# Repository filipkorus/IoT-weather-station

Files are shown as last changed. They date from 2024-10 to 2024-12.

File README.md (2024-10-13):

### Development
- [backend README](backend/README.md)
- [frontend README](frontend/README.md)

### Production
Build:
```shell
docker compose -f compose-master.yml -f compose-local.yml build
```

Start:
```shell
docker compose -f compose-master.yml -f compose-local.yml up -d
```

**NOTE:** [example-compose-local.yml](example-compose-local.yml) file is an example how [compose-local.yml](compose-local.yml) file should look like.

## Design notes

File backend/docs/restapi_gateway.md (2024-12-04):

# Gateway REST API Documentation

This API provides functionalities for managing gateways and their associated devices. Below are the details of each endpoint.

### 1. Fetch Gateway Pairing Code (to the Gateway)

**URL**: `/api/gateway/init`
**Method**: `POST`

#### Request
**Description**: This endpoint is used by a gateway device to initialize its pairing process. It generates or returns an existing pairing code if the gateway is not already paired with a user.

No request body is required because the gateway's API key is sent in the authorization header.

#### Response
- **Status Code**: `200 OK` is returned if the gateway is successfully initialized.
  ```json
  {
    "username": "string (username of the gateway owner)"
  }
  ```
- **Status Code**: `403 Forbidden` is returned if the gateway is not paired yet but the pairing code has been created.
  ```json
  {
    "pairingCode": "string (6-digit pairing code)"
  }
  ```
- **Status Code**: `500 Internal Server Error` is returned if the owner of the gateway is not found.
  ```json
    {
      "message": "Server Error: User owning gateway (id={gatewayId}) not found"
    }
  ```
- **Status Code**: `500 Internal Server Error` is returned if the pairing code could not be generated.
  ```json
    {
      "message": "Server Error: Pairing code could not be created"
    }
  ```
  
### 2. Insert Gateway Pairing Code (from the User)

**URL**: `/api/gateway/pariring-code`
**Method**: `POST`

#### Request
**Description**: This endpoint is used by a user to pair a gateway device with their account. The user must provide the 6-digit pairing code displayed on the gateway device.

This endpoint requires the user to be logged in, i.e. have a valid access token in the Authorization header (`Bearer accesstoken`).

- **Body Parameters**:
  ```json
  {
    "pairingCode": "string (6-digit pairing code inserted by the user)"
  }
  ```
  
#### Response
- **Status Code**: `200 OK` is returned if the gateway is successfully paired with the user.
  ```json
  {
    "message": "Gateway paired"
  }
  ```
- **Status Code**: `400 Bad Request` is returned if the `pairingCode` body field is missing or invalid.
  ```json
  {
    "message": "Missing or invalid body fields.",
    "errors": {
      "pairingCode": ["error message"]
    }
  }
  ```
- **Status Code**: `404 Not Found` is returned if the pairing code is invalid or the gateway is already paired or does not exist.
  ```json
  {
    "message": "Invalid pairing code"
  }
  ```
- **Status Code**: `500 Internal Server Error` is returned if the gateway could not be paired due to a server error.
  ```json
  {
    "message": "Server Error: Gateway could not be paired"
  }
  ```

### 3. Fetch Gateway Details

**URL**: `/api/gateway/:gatewayId`
**Method**: `GET`

#### Request
**Description**: This endpoint is used to fetch the details of a gateway device when gateway ID is provided. Else, it returns the details of all gateways associated with the logged user.

This endpoint requires the user to be logged in, i.e. have a valid access token in the Authorization header (`Bearer accesstoken`).

#### Response
- When `gatewayId` is provided:
  - **Status Code**: `200 OK` is returned if the gateway details are successfully fetched.
  ```json
  {
    "gateway": {
        "id": "string (gateway ID)",
        "name": "string (gateway name)",
        "latitude": "number (latitude) - can be null",
        "longitude": "number (longitude) - can be null",
        "isPaired": "boolean (gateway pairing status)",
        "isOnline": "boolean (gateway online status)",
        "lastOnline": "string (last online timestamp)",
        "userId": "string (user ID of the gateway owner)",
        "nodes": [{
            "id": "string (node ID)",
            "name": "string (node name)",
            "gatewayId": "string (gateway ID)",
            "NodeData": [{
                "batteryLevel": 5.5 // number - battery level in volts
            }]
        }]
    }
  }
  ```
    - **Status Code**: `404 Not Found` is returned if the gateway is not found.
    ```json
    {
        "message": "Gateway (id={gatewayId}) not found"
    }
    ```
- When `gatewayId` is not provided:
  - **Status Code**: `200 OK` is returned if gateways details are successfully fetched.
  ```json
  {
    "gateways": [{
        "id": "string (gateway ID)",
        "name": "string (gateway name)",
        "latitude": "number (latitude) - can be null",
        "longitude": "number (longitude) - can be null",
        "isPaired": "boolean (gateway pairing status)",
        "isOnline": "boolean (gateway online status)",
        "lastOnline": "string (last online timestamp)",
        "userId": "string (user ID of the gateway owner)",
        "nodes": [{
            "id": "string (node ID)",
            "name": "string (node name)",
            "gatewayId": "string (gateway ID)",
            "NodeData": [{
                "batteryLevel": 5.5 // number - battery level in volts
            }]
        }]
    }]
  }
  ```
    - **Status Code**: `500 Internal Server Error` is returned if the server could not fetch the gateways.
    ```json
    {
        "message": "Server Error: Gateways could not be retrieved"
    }
    ```
  
### 4. Update Gateway Name, Latitude, and Longitude

**URL**: `/api/gateway/:gatewayId`
**Method**: `PUT`

#### Request
**Description**: This endpoint is used to update the name, latitude, and longitude of a gateway device when gateway ID is provided.

This endpoint requires the user to be logged in, i.e. have a valid access token in the Authorization header (`Bearer accesstoken`).

- **Body Parameters**:
  ```json
  {
    "name": "string (new gateway name) - optional",
    "latitude": "number (new latitude) - optional",
    "longitude": "number (new longitude) - optional"
  }
  ```
  
#### Response
- **Status Code**: `200 OK` is returned if the gateway name and/or latitude and longitude are successfully updated.
  ```json
  {
    "message": "Gateway name and location updated" // or "Gateway name updated" or "Gateway location updated"
  }
  ```

- **Status Code**: `400 Bad Request` is returned if the `name`, `latitude`, and `longitude` body fields are invalid.
  ```json
  {
    "message": "Missing or invalid body fields.",
    "errors": {
      "name": ["error message"],
      "latitude": ["error message"],
      "longitude": ["error message"]
    }
  }
  ```

- **Status Code**: `400 Bad Request` is also returned if no changes were made to the gateway.
  ```json
  {
    "message": "No changes made"
  }
  ```

- **Status Code**: `404 Not Found` is returned if the gateway is not found.
  ```json
  {
    "message": "Gateway (id={gatewayId}) not found"
  }
  ```
- **Status Code**: `500 Internal Server Error` is returned if the gateway name could not be updated due to a server error.
  ```json
  {
    "message": "Server Error: Gateway name could not be updated"
  }
  ```
  
### 5. Fetch Gateway Public Details

**URL**: `/api/public-gateway/:gatewayId`
**Method**: `GET`

#### Request
**Description**: This endpoint is used to fetch the public details of a gateway device when gateway ID is provided. Else, it returns the public details of all gateways.

This endpoint does not require to be logged in.

#### Response
- When `gatewayId` is provided:
  - **Status Code**: `200 OK` is returned if gateways public details are successfully fetched.
  ```json
  {
    "gateway": {
        "id": "string (gateway ID)",
        "name": "string (gateway name)",
        "latitude": "number (latitude) - can be null",
        "longitude": "number (longitude) - can be null",
        "isPaired": "boolean (gateway pairing status)",
        "isOnline": "boolean (gateway online status)",
        "lastOnline": "string (last online timestamp)",
        "userId": "string (user ID of the gateway owner)",
        "nodes": [{
            "id": "string (node ID)",
            "name": "string (node name)",
            "gatewayId": "string (gateway ID)"
        }],
        "likes": "number (number of likes)",
        "haveYouLiked": false, // boolean indication whether the user has already liked the gateway today
        "sensorData": [{ // last 5 sensor readings
            "id": 123, // number - sensor data ID
            "created": "2024-11-13T15:41:34.588Z", // string - timestamp of the sensor data
            "batteryLevel": 2.33, // number - battery level in volts
            "nodeId": "string (node ID)",
            "temperature": 23.5, // number - temperature in Celsius
            "humidity": 60, // number - humidity in percentage
            "pressure": 1013.25, // number - pressure in hPa
            "snowDepth": 0, // number - snow depth in mm (or cm)
            "pm1": 5, // number - PM1.0 in µg/m³
            "pm25": 12, // number - PM2.5 in µg/m³
            "pm10": 18 // number - PM10 in µg/m³
        }]
    }
  }
  ```
  - **Status Code**: `404 Not Found` is returned if the gateway is not found.
    ```json
    {
        "message": "Gateway (id=${gatewayId}) not found"
    }
    ```
- When `gatewayId` is not provided:
    - **Status Code**: `200 OK` is returned if gateways public details are successfully fetched.
    ```json
    {
        "gateways": [{
            "id": "string (gateway ID)",
            "name": "string (gateway name)",
            "latitude": "number (latitude) - can be null",
            "longitude": "number (longitude) - can be null",
            "isPaired": "boolean (gateway pairing status)",
            "isOnline": "boolean (gateway online status)",
            "lastOnline": "string (last online timestamp)",
            "userId": "string (user ID of the gateway owner)",
            "nodes": [{
                "id": "string (node ID)",
                "name": "string (node name)",
                "gatewayId": "string (gateway ID)"
            }],
            "likes": "number (number of likes)",
            "haveYouLiked": false, // boolean indication whether the user has already liked the gateway today
            "sensorData": [{ // last 5 sensor readings
                "id": 123, // number - sensor data ID
                "created": "2024-11-13T15:41:34.588Z", // string - timestamp of the sensor data
                "batteryLevel": 2.33, // number - battery level in volts
                "nodeId": "string (node ID)",
                "temperature": 23.5, // number - temperature in Celsius
                "humidity": 60, // number - humidity in percentage
                "pressure": 1013.25, // number - pressure in hPa
                "snowDepth": 0, // number - snow depth in mm (or cm)
                "pm1": 5, // number - PM1.0 in µg/m³
                "pm25": 12, // number - PM2.5 in µg/m³
                "pm10": 18 // number - PM10 in µg/m³
            }]
        }]
    }
    ```
    - **Status Code**: `500 Internal Server Error` is returned if the server could not fetch the gateways.
    ```json
    {
        "message": "Server Error: Gateways could not be retrieved"
    }
    ```

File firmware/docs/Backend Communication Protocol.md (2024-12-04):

# Connection to backend

All frames will have a special key to auth on the backend side.

Node ID (unique serial number): N*rrrrmmdd(00-FF)*

Gateway ID (unique serial number): G*rrrrmmdd(00-FF)*

The gateway initialises the connection by sending the `Init Frame`. If the gateway is not paired to any account, the backend returns the pairing code, which the gateway displays on the LCD screen.

The user enters the code on the website to pair it with his account. After the gateway restarts, it sends the `Init frame` again. The backend returns user data, and then the gateway starts the WS connection.

The user can pair nodes with the gateway with the button located on the case. A node sends his NID number via ESP-NOW to the gateway. The gateway saves this NID to EEPROM as a trusted node.

The gateway sends a frame via WS containing sensor data and node serial number to the backend. The backend will create a node object if it does not exist, then log data from sensors.

Node object contains also `last_message` and `battery_level` used to check if the node is alive.

### `POST` Init Frame:

##### Request:

    {
    	uid: *GatewayId*
    }

##### Response:

If not paired:
Status: `403`

    {
    	pair_code: *6 char code*
    }

If paired:
Status: `200`

    {
    	user_name: *Name of the user*
    }

### `WS` Data Frame:

#### Gateway to backend:

    {
    	type: 'sensors'
    	node_id:
    	battery_level: 5-8,4 (V)
    	temperature: -5.5 (*C)
    	humidity: 50 (0-100%)
    	pressure: 1010 (hPa)
    	snow_depth: 50 (cm)
    	pm1: ?
    	pm25: ?
    	pm10: ?
    }

#### Backend to Gateway:

    {
    	type: 'likes'
    	likes: *int*
    }

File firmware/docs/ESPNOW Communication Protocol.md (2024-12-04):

# Frame struct

```C++
typedef struct struct_message
{
    char nodeId[16];
    float batteryLevel; // volts
    float temperature;  // °C
    float humidity;     // %
    float pressure;     // hPa
    int32_t snowDepth;  // cm
    uint32_t pm1;       // ug/m³
    uint32_t pm25;      // ug/m³
    uint32_t pm10;      // ug/m³
    bool pair;
} struct_message;
```

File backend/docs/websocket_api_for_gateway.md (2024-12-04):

# Gateway WebSocket API Documentation

This API provides functionalities for the gateway WebSocket server. Below are the details of each type of message.

Authentication is done using the gateway's API key in the `Authorization` header.

### 1. Sending Node sensor data (from the Gateway, to the Server)

**Description**: Sends sensor data from a node to the server.

**JSON Body**:
```json
{
  "type": "sensors",
  "nodeId": "Nrrrrmmdd(00-FF)", // string (Node ID)
  "batteryLevel":  5.5,   // float (Battery level in volts)
  "temperature": 25.5,    // float (Temperature in Celsius)
  "humidity":  70.5,      // float (Humidity in percentage)
  "pressure": 1013.25,    // float (Pressure in hPa)
  "snowDepth":  42.0,     // float (Snow depth in cm)
  "pm1": 10.0,            // float (PM1 in µg/m³)
  "pm25":  25.0,          // float (PM2.5 in µg/m³)
  "pm10": 50.0,           // float (PM10 in µg/m³)
}
```

### 2. Receiving like count data (from the Server, to the Gateway)

**Description**: Sends the like count data to the gateway.

**JSON Body**:
```json
{
  "type": "likes",
  "gatewayId": "Grrrrmmdd(00-FF)", // string (Node ID)
  "likes":  10 // integer (Like count)
}
```

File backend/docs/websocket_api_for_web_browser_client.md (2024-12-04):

# Web Browser Client WebSocket API Documentation

This API provides functionalities for the web browser client WebSocket server. Below are the details of each type of message.

Every client trying to connect without an API key in the `Authorization` header, is assumed to be a web browser client.

### 1. Receiving live sensor data (from the Server, to the Web Browser Client)

**Description**: Sends live sensor data to the web browser client.

**JSON Body**:
```json
{
  "type": "sensors-to-client",
  "gatewayId": "Grrrrmmdd(00-FF)", // string (Gateway ID)
  "nodeId": "Nrrrrmmdd(00-FF)",    // string (Node ID)
  "sensorData": {
    "batteryLevel":  5.5,   // float (Battery level in volts)
    "temperature": 25.5,    // float (Temperature in Celsius)
    "humidity":  70.5,      // float (Humidity in percentage)
    "pressure": 1013.25,    // float (Pressure in hPa)
    "snowDepth":  42.0,     // float (Snow depth in cm)
    "pm1": 10.0,            // float (PM1 in µg/m³)
    "pm25":  25.0,          // float (PM2.5 in µg/m³)
    "pm10": 50.0,            // float (PM10 in µg/m³)
    "created": "2024-11-13T15:41:34.588Z" // string - timestamp of the sensor data",    // string (Date and time of the measurement)
  }
}
```

### 2. Sending 'like' (from the Web Browser Client, to the Server)

**Description**: Sends the like to the server.

**Request JSON Body**:
```json
{
  "type": "likes",
  "gatewayId": "Grrrrmmdd(00-FF)" // string (Gateway ID)
}
```

**Response JSON Body**:
- If the like was successfully sent (FYI: one like from one `(IP address, User Agent)` pair per day per each Gateway is allowed):
```json
{
  "type": "likes",
  "gatewayId": "Grrrrmmdd(00-FF)", // string (Gateway ID)
  "likes":  10 // integer (Like count)
}
```

- Else, if the like was not successful - e.g., the user has already liked:
```json
{
  "type": "likes-error-response",
  "error": true,
  "gatewayId": "Grrrrmmdd(00-FF)", // string (Gateway ID)
  "message": "You have already liked" // string (Error message)
}
```

### 3. Sending 'remove like' request (from the Web Browser Client, to the Server)

**Description**: Sends the 'remove like' request to the server.

**Request JSON Body**:
```json
{
  "type": "dislike",
  "gatewayId": "Grrrrmmdd(00-FF)" // string (Gateway ID)
}
```

**Response JSON Body**:
- If the request was successful and the like was removed:
```json
{
  "type": "likes",
  "gatewayId": "Grrrrmmdd(00-FF)", // string (Gateway ID)
  "likes":  9 // integer (Like count)
}
```

- Else, if the request was not successful - e.g., the user has not liked yet:
```json
{
  "type": "dislike-error-response",
  "error": true,
  "gatewayId": "Grrrrmmdd(00-FF)", // string (Gateway ID)
  "message": "You have not liked yet" // string (Error message)
}
```

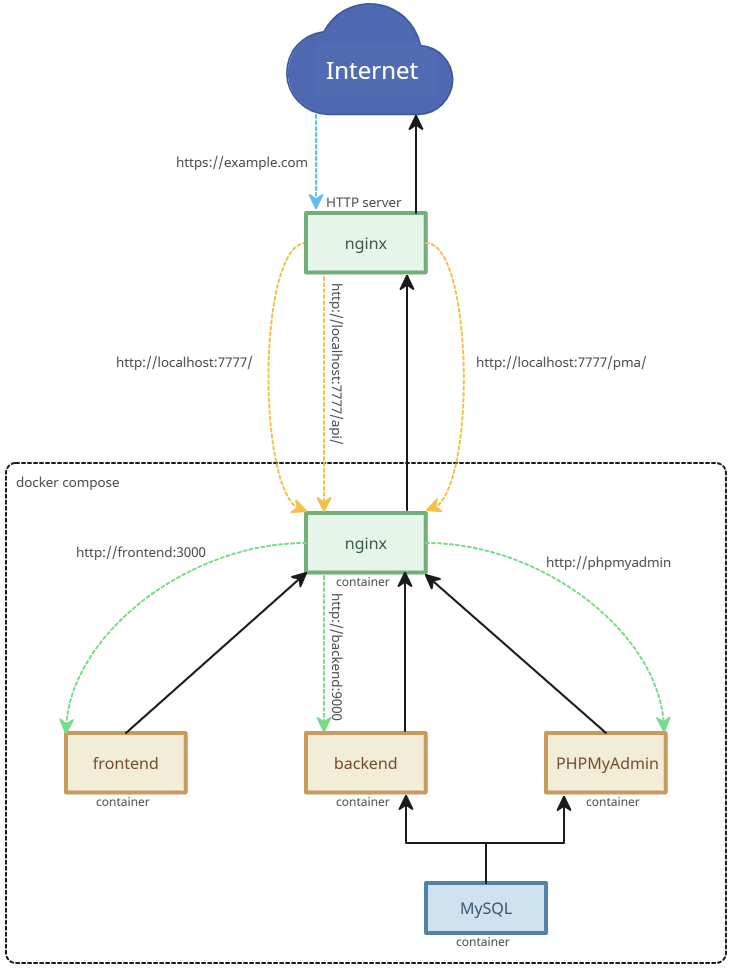
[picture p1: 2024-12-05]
backend/docs/architecture.png

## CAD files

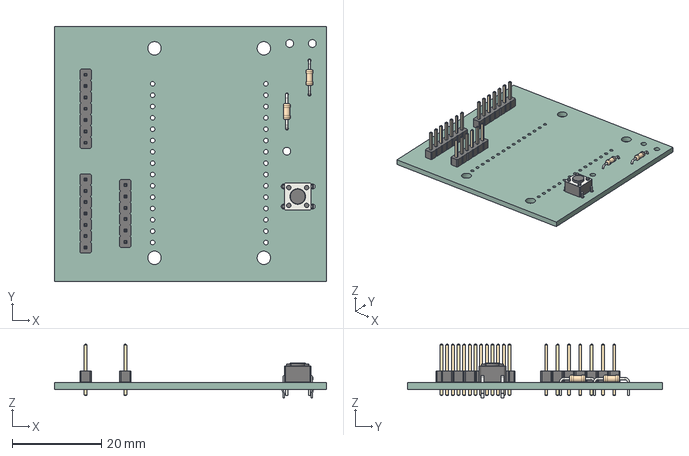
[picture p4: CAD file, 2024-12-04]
PCBs/node/node.step
61.0 x 57.2 x 12.0 mm
node PCB

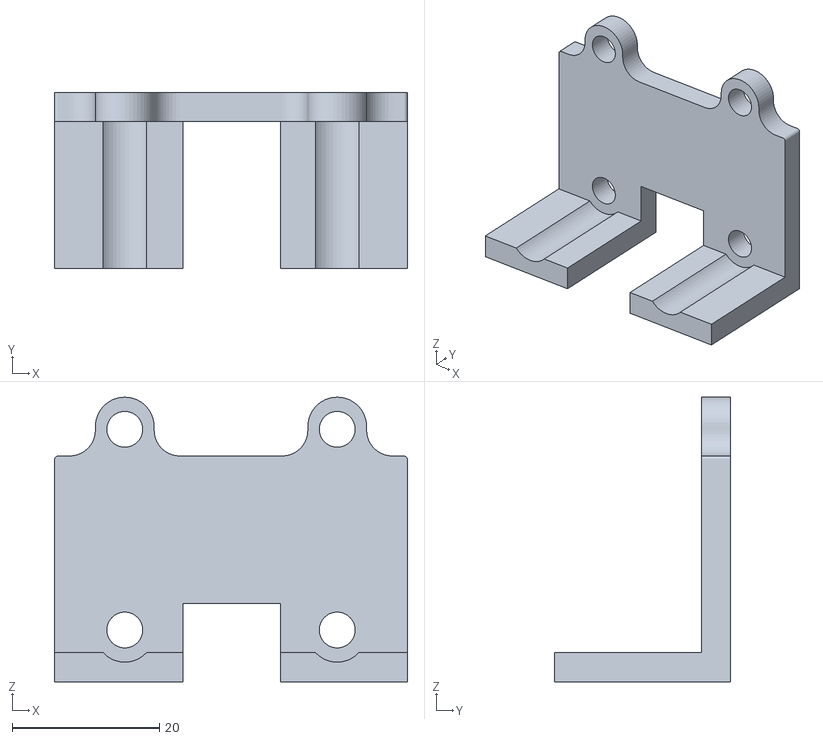
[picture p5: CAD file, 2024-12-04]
STL/LidarMount.stl
48.0 x 24.0 x 38.7

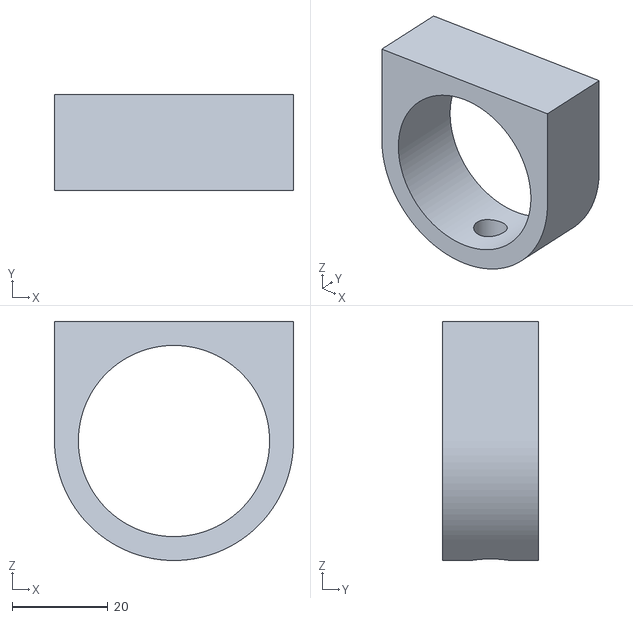
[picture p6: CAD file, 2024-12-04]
STL/LidMount.stl
50.0 x 20.0 x 50.0

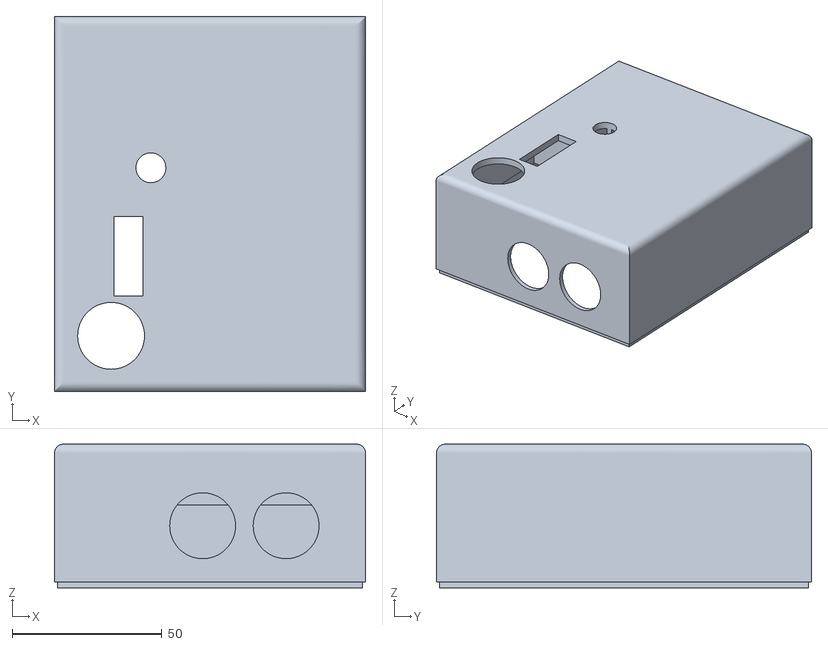
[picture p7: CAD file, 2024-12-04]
STL/case.stl
103.8 x 125.2 x 48.0

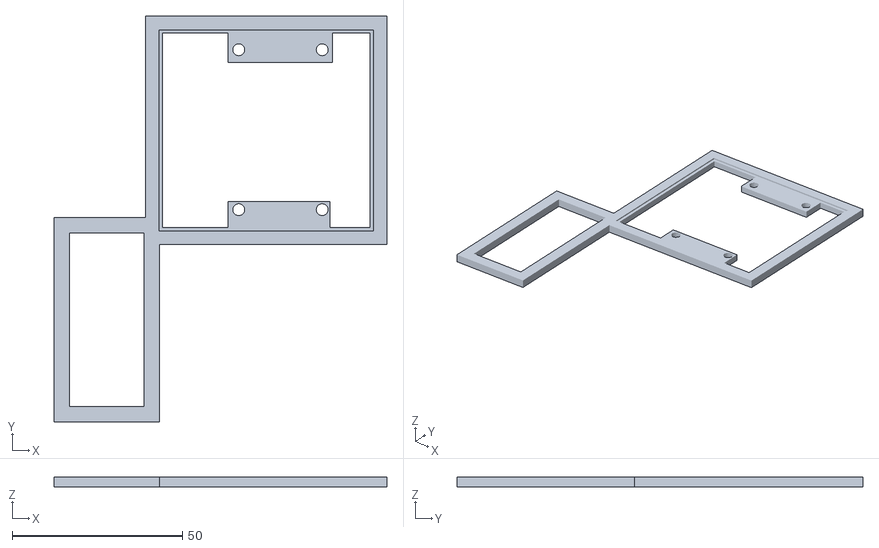
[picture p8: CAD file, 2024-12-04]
STL/backplate.stl
97.8 x 119.2 x 3.00

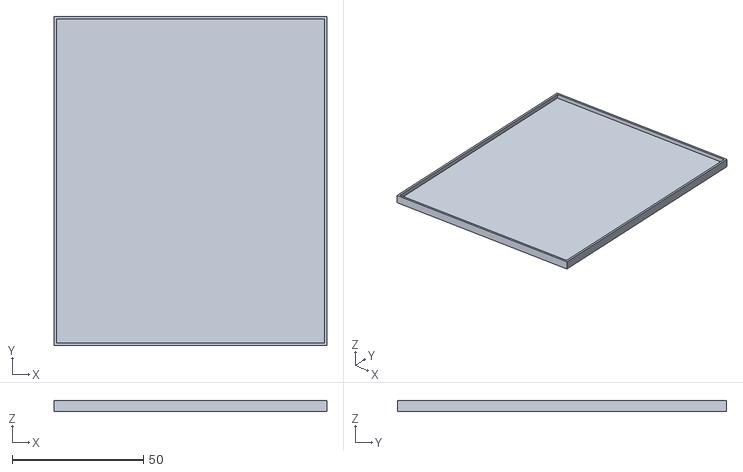
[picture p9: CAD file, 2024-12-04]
STL/Lid.stl
103.8 x 125.2 x 4.00

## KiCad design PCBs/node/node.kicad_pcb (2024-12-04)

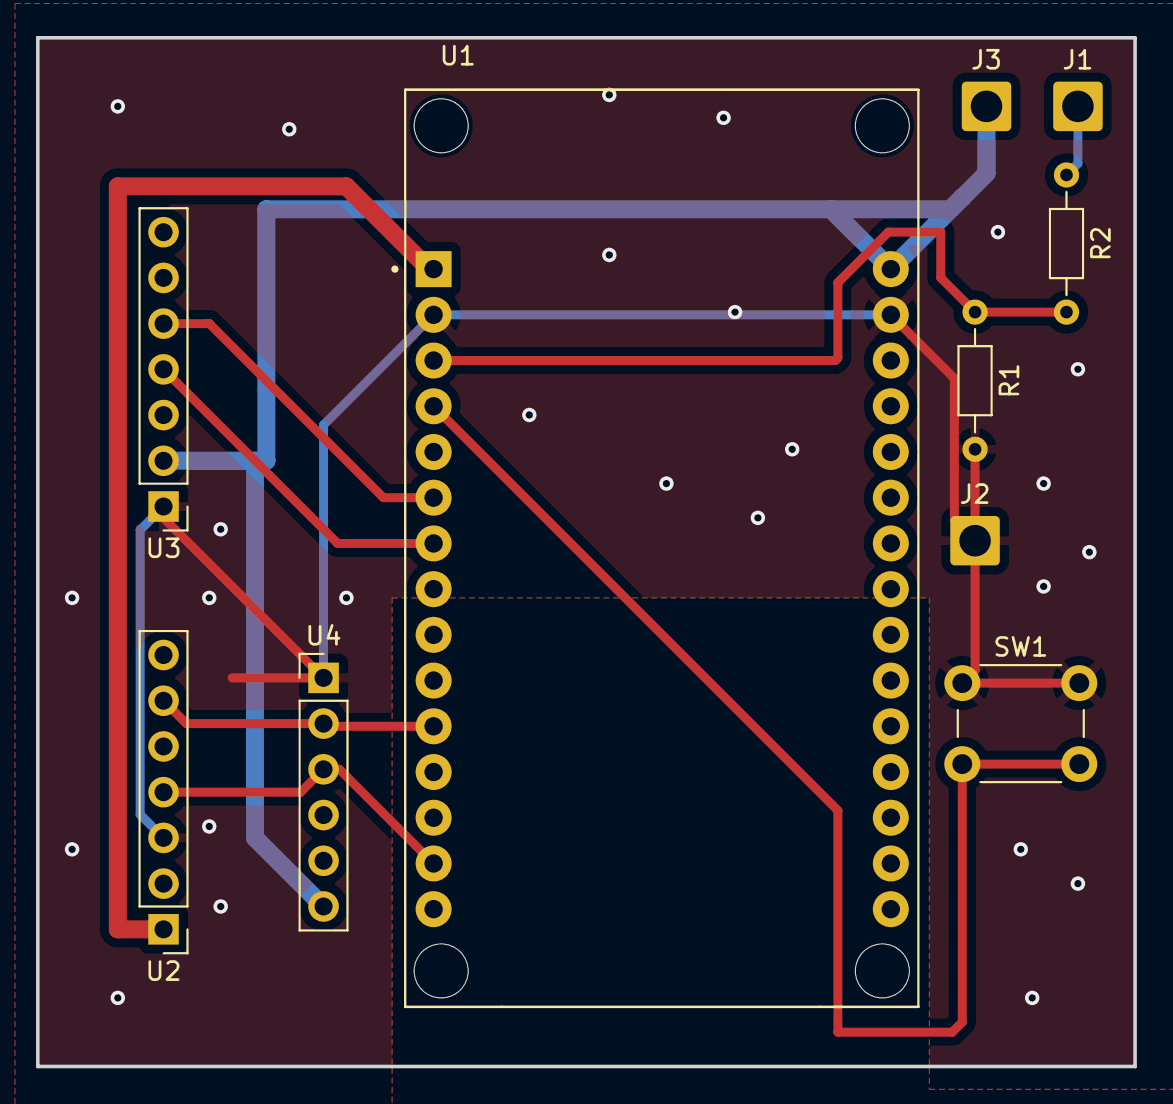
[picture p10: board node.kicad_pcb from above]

Board: 2 copper layers, 61.0 x 57.2 mm, 10 parts (0 on the bottom side), 10 nets.

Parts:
J1: Bat+; SolderWire-1sqmm_1x01_D1.4mm_OD2.7mm
J2: GND; SolderWire-1sqmm_1x01_D1.4mm_OD2.7mm
J3: 5V; SolderWire-1sqmm_1x01_D1.4mm_OD2.7mm
R1: 10k; R_Axial_DIN0204_L3.6mm_D1.6mm_P7.62mm_Horizontal
R2: 20k; R_Axial_DIN0204_L3.6mm_D1.6mm_P7.62mm_Horizontal
SW1: SW_Push; SW_PUSH_6mm
U1: ESP32-DEVKIT-V1; MODULE_ESP32_DEVKIT_V1
U2: BME280; PinHeader_1x07_P2.54mm_Vertical
U3: pm25sensor; PinHeader_1x07_P2.54mm_Vertical
U4: lidar; PinHeader_1x06_P2.54mm_Vertical

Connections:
+3.3V: U1.1 (3V3), U2.1 (VIN)
+5V: J3.1, U1.30 (VIN), U3.2 (VCC), U4.6 (VCC)
GND: J2.1, R1.2, SW1.1, U1.2 (GND), U1.29 (GND), U2.3 (GND), U3.1 (GND), U4.1 (GND)
unnamed: J1.1, R2.1
unnamed: SW1.2, U1.4 (D2)
unnamed: R1.1, R2.2, U1.3 (D15)
unnamed: U1.11 (D21), U2.6 (SDI), U4.2 (SDA)
unnamed: U1.14 (D22), U2.4 (SCK), U4.3 (SCL)
unnamed: U1.6 (RX2), U3.5 (TX)
unnamed: U1.7 (TX2), U3.4 (RX)

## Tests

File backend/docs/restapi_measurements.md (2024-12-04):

# Measurements REST API Documentation

This API provides functionalities for reading historical measurements. Below are the details of each endpoint.

### 1. Fetch measurements for a given node

**URL**: `/api/measurements/node/<node_id>`
**Method**: `GET`

#### Request

**Description**: This endpoint is used for fetching measurements for a given node.

- **Query Parameters**:
  - `startDate`: Start time of the measurements (optional), format: `YYYY-MM-DDTHH:mm:ss`, default: 1 week ago
  - `endDate`: End time of the measurements (optional), format: `YYYY-MM-DDTHH:mm:ss`, default: now

#### Response

- When the node_id is correct and there are measurements for the given node:

  - **Status Code**: 200
  - **Body**:

    ```json
    {
      "success": true,
      "msg": "Measurements for node ${node_id}",
      "measurements": [
        {
          "id": "", // string, (unique identifier of the measurement)
          "nodeId": "", // string, (unique identifier of the node)
          "batteryLevel": 5.5, // float (Battery level in volts)
          "temperature": 25.5, // float (Temperature in Celsius)
          "humidity": 70.5, // float (Humidity in percentage)
          "pressure": 1013.25, // float (Pressure in hPa)
          "snowDepth": 42.0, // float (Snow depth in cm)
          "pm1": 10.0, // float (PM1 in µg/m³)
          "pm25": 25.0, // float (PM2.5 in µg/m³)
          "pm10": 50.0, // float (PM10 in µg/m³)
          "created": "YYYY-MM-DDTHH:mm:ss" // string - timestamp of the sensor data",    // string (Date and time of the measurement)
        },
        {
          "id": "", // string, (unique identifier of the measurement)
          "nodeId": "", // string, (unique identifier of the node)
          "batteryLevel": 5.5, // float (Battery level in volts)
          "temperature": 25.5, // float (Temperature in Celsius)
          "humidity": 70.5, // float (Humidity in percentage)
          "pressure": 1013.25, // float (Pressure in hPa)
          "snowDepth": 42.0, // float (Snow depth in cm)
          "pm1": 10.0, // float (PM1 in µg/m³)
          "pm25": 25.0, // float (PM2.5 in µg/m³)
          "pm10": 50.0, // float (PM10 in µg/m³)
          "created": "YYYY-MM-DDTHH:mm:ss" // string - timestamp of the sensor data",    // string (Date and time of the measurement)
        }
      ]
    }
    ```

    - When there are no measurements for the given node:

      - **Status Code**: 200
      - **Body**:

        ```json
        {
          "success": true,
          "msg": "Measurements for Node ID: ${id}",
          "measurements": []
        }
        ```

    - When the node_id is incorrect:
      - **Status Code**: 404
      - **Body**:
        ```json
        {
          "success": false,
          "message": "Node ID: ${id} not found"
        }
        ```
    - When the measurements aren't found for other reasons:

      - **Status Code**: 404
      - **Body**:

        ```json
        {
          "success": false,
          "message": "Measurements not found"
        }
        ```

    - When the request path is invalid:

      - **Status Code**: 400
      - **Body**:

        ```json
        {
          "success": false,
          "message": "Invalid request path"
        }
        ```

    - When there's an internal server error:

      - **Status Code**: 500
      - **Body**:

        ```json
        {
          "success": false,
          "message": "Error retrieving measurements"
        }
        ```

### 2. Fetch measurements from nodes connected to a given gateway

**URL**: `/api/measurements/gateway/<gateway_id>`
**Method**: `GET`

#### Request

**Description**: This endpoint is used for fetching measurements from all nodes connected to that gateway.

- **Query Parameters**:
  - `startDate`: Start time of the measurements (optional), format: `YYYY-MM-DDTHH:mm:ss`, default: 1 week ago
  - `endDate`: End time of the measurements (optional), format: `YYYY-MM-DDTHH:mm:ss`, default: now

#### Response

- When the gateway_id is correct and there are measurements for the given gateway:

  - **Status Code**: 200
  - **Body**:

    ```json
    {
      "success": true,
      "msg": "Measurements for gateway ${gateway_id}",
      "measurements": [
        {
          "id": "", // string, (unique identifier of the measurement)
          "nodeId": "", // string, (unique identifier of the node)
          "batteryLevel": 5.5, // float (Battery level in volts)
          "temperature": 25.5, // float (Temperature in Celsius)
          "humidity": 70.5, // float (Humidity in percentage)
          "pressure": 1013.25, // float (Pressure in hPa)
          "snowDepth": 42.0, // float (Snow depth in cm)
          "pm1": 10.0, // float (PM1 in µg/m³)
          "pm25": 25.0, // float (PM2.5 in µg/m³)
          "pm10": 50.0, // float (PM10 in µg/m³)
          "created": "YYYY-MM-DDTHH:mm:ss" // string (Date and time of the measurement)
        },
        {
          "id": "", // string, (unique identifier of the measurement)
          "nodeId": "", // string, (unique identifier of the node)
          "batteryLevel": 5.5, // float (Battery level in volts)
          "temperature": 25.5, // float (Temperature in Celsius)
          "humidity": 70.5, // float (Humidity in percentage)
          "pressure": 1013.25, // float (Pressure in hPa)
          "snowDepth": 42.0, // float (Snow depth in cm)
          "pm1": 10.0, // float (PM1 in µg/m³)
          "pm25": 25.0, // float (PM2.5 in µg/m³)
          "pm10": 50.0, // float (PM10 in µg/m³)
          "created": "YYYY-MM-DDTHH:mm:ss" // string (Date and time of the measurement)
        }
      ]
    }
    ```

    - When there are no measurements for the given gateway:
      - **Status Code**: 200
      - **Body**:
        ```json
        {
          "success": true,
          "msg": "Measurements for Gateway ID: ${id}",
          "measurements": []
        }
        ```
    - When the node_id is incorrect:
      - **Status Code**: 404
      - **Body**:
        ```json
        {
          "success": false,
          "message": "Gateway ID: ${id} not found"
        }
        ```
    - When the measurements aren't found for other reasons:
      - **Status Code**: 404
      - **Body**:
        ```json
        {
          "success": false,
          "message": "Measurements not found"
        }
        ```
    - When the request path is invalid:
      - **Status Code**: 400
      - **Body**:
        ```json
        {
          "success": false,
          "message": "Invalid request path"
        }
        ```
    - When there's an internal server error:
      - **Status Code**: 500
      - **Body**:
        ```json
        {
          "success": false,
          "message": "Error retrieving measurements"
        }
        ```

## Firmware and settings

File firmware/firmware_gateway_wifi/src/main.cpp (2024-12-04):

#include <Arduino.h>
#include <WiFi.h>
#include <esp_wifi.h>
#include <WiFiManager.h>
#include <HTTPClient.h>
#include <ArduinoJson.h>
#include <GlobalVar.h>
#include <WebSocketsClient.h>
#include <LiquidCrystal_I2C.h>
#include <EEPROM.h>

#define USE_SERIAL Serial
WebSocketsClient webSocket;
LiquidCrystal_I2C lcd(0x27, 12, 2);

#define BUTTON_PIN 15

#define NODE_ID_SIZE 16
#define NUM_NODES 10
const int EEPROM_SIZE = NUM_NODES * NODE_ID_SIZE + 1;

// Function to read a Node ID from EEPROM at a given index
void readNodeID(int index, char *buffer)
{
  int offset = index * NODE_ID_SIZE + 1; // Calculate offset
  for (int i = 0; i < NODE_ID_SIZE; ++i)
  {
    EEPROM.get(offset + i, buffer[i]); // Read Node ID byte by byte
  }
}

void saveNodeID(int index, const char *nodeID)
{
  int offset = index * NODE_ID_SIZE + 1; // Calculate offset based on Node ID size
  for (int i = 0; i < NODE_ID_SIZE; ++i)
  {
    EEPROM.put(offset + i, nodeID[i]);
  }
  EEPROM.commit(); // Save changes to EEPROM

  Serial.print("Paired: ");
  Serial.println(nodeID);
}

void saveNextNodeID(const char *nodeID)
{
  int nextIndex = EEPROM.read(0);
  saveNodeID(nextIndex + 1, nodeID);
  EEPROM.put(0, nextIndex + 1);
  EEPROM.commit();
}

// Function to search for a Node ID in EEPROM, returns the index if found, or -1 if not found
int searchNodeID(const char *nodeIDToSearch)
{
  char buffer[NODE_ID_SIZE] = {0}; // Temporary buffer to store Node ID during comparison

  for (int i = 0; i < NUM_NODES; ++i)
  {
    readNodeID(i, buffer); // Read Node ID from EEPROM
    if (strncmp(buffer, nodeIDToSearch, NODE_ID_SIZE) == 0)
    {
      return i; // Match found, return index
    }
  }

  return -1; // Node ID not found
}

void resetEEPROM()
{
  for (int i = 0; i < EEPROM_SIZE; i++)
  {
    EEPROM.put(i, 0);
  }
  EEPROM.commit();
}

float hum = 0.f;
float temp = 0.f;
int likes = 0;
bool rxNow = false;
void updateLCD()
{
  lcd.clear();
  lcd.setCursor(0, 0);
  lcd.print("Likes: ");
  lcd.print(likes);
  if (rxNow)
  {
    lcd.print(" ");
    lcd.write(1);
  }
  lcd.setCursor(0, 1);
  lcd.printf("%.1f", temp);
  lcd.write(0xdf);
  lcd.print("C ");
  lcd.printf("%.1f", hum);
  lcd.print("%");
  if (rxNow)
  {
    delay(500);
    rxNow = false;
    updateLCD();
  }
}
void webSocketEvent(WStype_t type, uint8_t *payload, size_t length)
{
  DynamicJsonDocument doc(1024);
  switch (type)
  {
  case WStype_DISCONNECTED:
    USE_SERIAL.printf("[WSc] Disconnected!\n");
    break;
  case WStype_CONNECTED:
    USE_SERIAL.printf("[WSc] Connected to url: %s\n", payload);
    break;

  case WStype_TEXT:
    USE_SERIAL.printf("[WSc] get text: %s\n", payload);

    deserializeJson(doc, payload);

    if (strcmp(doc["gatewayId"], UID) != 0)
    {
      Serial.println("tak sie nie robi");
      return;
    }

    if (strcmp(doc["type"], "likes") == 0)
    {
      Serial.println("[Comm] Init frame received");
      likes = doc["likes"].as<int>();
      updateLCD();
    }

    break;
  case WStype_BIN:
  case WStype_ERROR:
  case WStype_FRAGMENT_TEXT_START:
  case WStype_FRAGMENT_BIN_START:
  case WStype_FRAGMENT:
  case WStype_FRAGMENT_FIN:
    break;
  }
}

void WebSocketInit()
{
  Serial.println("[Comm] Connecting to ws backend server...");

#if WSS == true
  webSocket.beginSSL(BACKEND_IP, 443, "/ws");
#else
  webSocket.begin(BACKEND_IP, 80, "/ws");
#endif

  webSocket.onEvent(webSocketEvent);
  webSocket.setAuthorization(AUTH_TOKEN);
  webSocket.loop();

  while (!webSocket.isConnected())
  {
    webSocket.loop();
    delay(10);
  }
}

bool initBackend()
{
  bool success = false;
  HTTPClient http;

  http.begin("https://iot.fkor.us/api/gateway/init"); // Specify the URL
  http.addHeader("Content-Type", "application/json"); // Set content type
  http.addHeader("Authorization", AUTH_TOKEN);

  DynamicJsonDocument jsonBuffer(1024);
  jsonBuffer["uid"] = UID;
  String jsonOutput;
  serializeJson(jsonBuffer, jsonOutput);
  int httpCode = http.POST(jsonOutput); // Make the request

  if (httpCode > 0)
  { // Check for a successful response
    String payload = http.getString();
    Serial.println("HTTP POST request successful");
    Serial.println(payload);

    // Allocate a JSON document for parsing.
    const size_t capacity = JSON_OBJECT_SIZE(10) + 256;
    DynamicJsonDocument doc(capacity);

    // Parse the JSON object.
    DeserializationError error = deserializeJson(doc, payload);
    if (error)
    {
      Serial.print("deserializeJson() failed: ");
      Serial.println(error.c_str());
      return success;
    }

    // Access values from the JSON object, for example:
    success = doc["success"].as<bool>();
    if (!doc["success"])
    {
      const char *pairingCode = doc["pairingCode"].as<const char *>(); // Substitute with your JSON key
      Serial.println(pairingCode);

      lcd.clear();
      lcd.setCursor(0, 0);
      lcd.print("Pairing code: ");
      lcd.setCursor(0, 1);
      lcd.print(pairingCode);
    }
    else
    {
      const char *username = doc["username"].as<const char *>();

      lcd.clear();
      lcd.setCursor(0, 0);
      lcd.print("Hello ");
      lcd.print(username);
      lcd.setCursor(0, 1);
      lcd.print("nodes: ");
      uint8_t nextIndex;
      EEPROM.get(0, nextIndex);
      Serial.print("nextIndex ");
      Serial.println(nextIndex);
      lcd.print(nextIndex);
    }
  }
  else
  {
    Serial.print("Error on HTTP request: ");
    Serial.println(httpCode);
  }

  http.end();

  return success;
}

byte wifiSymbol[] = {B00000, B01110, B10001, B00100, B01010, B00000, B00100, B00000};

void setup()
{
  WiFi.mode(WIFI_STA);
  Serial.begin(115200);
  Serial2.begin(115200);

  if (!EEPROM.begin(EEPROM_SIZE))
  {
    Serial.println("Failed to initialize EEPROM");
    return;
  }

  pinMode(BUTTON_PIN, INPUT_PULLUP);

  lcd.init();
  lcd.backlight();
  lcd.setCursor(0, 0);
  lcd.clear();
  lcd.print("Init");
  lcd.setCursor(0, 1);
  lcd.print(UID);
  bool res;
  WiFiManager wm;
  res = wm.autoConnect("esp32", "12345678");

  if (!res)
  {
    Serial.println("Failed to connect");
  }
  else
  {
    Serial.println("connected...yeey :)");
  }

  int channel = WiFi.channel();
  Serial.print("Current Wi-Fi Channel: ");
  Serial.println(channel);

  lcd.clear();
  lcd.print("Connected");
  lcd.setCursor(0, 1);
  lcd.print("to WiFi");

  lcd.createChar(1, wifiSymbol);

  if (!initBackend())
  {
    Serial.println("displaying pair code");
    for (;;)
    {
      delay(1000);
    }
  }

  WebSocketInit();
}

uint8_t resetCount = 6;
bool pairMode = false;
String receivedMessage = "";

void loop()
{
  if (!digitalRead(BUTTON_PIN))
  {
    resetCount--;
    if (resetCount >= 5)
    {
      lcd.clear();
      lcd.print("pair mode");
    }
    else
    {
      lcd.clear();
      lcd.print("reset in: ");
      lcd.print(resetCount);
      lcd.print(" s");
    }

    delay(1000);
    if (resetCount <= 0)
    {
      Serial.println("reset");
      resetEEPROM();
      int nextIndex = EEPROM.read(0);
      Serial.println(nextIndex);
      if (nextIndex == 0)
      {
        lcd.clear();
        lcd.print("reset OK");
        delay(3000);
        ESP.restart();
      }
    }
    return;
  }
  else
  {
    if (resetCount == 5)
    {
      pairMode = true;
      Serial.println("pair mode");
    }
    if (resetCount < 5)
    {
      updateLCD();
    }
    resetCount = 6;
  }

  webSocket.loop();
  // delay(2000);

  // Check if data is available in the Serial buffer
  while (Serial2.available())
  {
    DynamicJsonDocument doc(2048);
    char incomingChar = Serial2.read(); // Read each character from the buffer

    if (incomingChar == '\n')
    { // Check if the user pressed Enter (new line character)
      // Print the message
      deserializeJson(doc, receivedMessage);
      rxNow = true;

      auto nodeId = doc["nodeId"].as<const char *>();
      auto pair = doc["pair"].as<bool>();
      Serial.print(nodeId);
      Serial.print(" pair?: ");
      Serial.println(pair);

      if (pairMode && pair)
      {
        saveNextNodeID(nodeId);
        lcd.clear();
        lcd.print("Paired: ");
        lcd.setCursor(0, 1);
        lcd.print(nodeId);
        pairMode = false;
        delay(2000);
        updateLCD();
      }

      if (searchNodeID(nodeId) == -1)
      {
        Serial.println("Tak sie nie robi");
        receivedMessage = "";
        return;
      }

      auto snowDepth = 60 - doc["snowDepth"].as<int32_t>();
      Serial.print("og snowDepth: ");
      Serial.println(snowDepth);
      snowDepth += 35;
      snowDepth = snowDepth * 0.522f + 8.437f;
      doc["snowDepth"] = snowDepth < 5 ? 0 : snowDepth;

      hum = doc["humidity"].as<float>();
      temp = doc["temperature"].as<float>() - 8.f;

      doc["temperature"] = temp;

      String jsonOutput;
      serializeJson(doc, jsonOutput);
      Serial.println(jsonOutput);
      webSocket.sendTXT(jsonOutput);
      updateLCD();
      // Clear the message buffer for the next input
      receivedMessage = "";
    }
    else
    {
      // Append the character to the message string
      receivedMessage += incomingChar;
    }
  }
}

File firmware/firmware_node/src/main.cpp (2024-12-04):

#include <Arduino.h>
#include <SPI.h>
#include <Wire.h>
#include <SPI.h>
#include <Adafruit_Sensor.h>
#include <Adafruit_BME280.h>
#include <WiFi.h>
#include <esp_wifi.h>
#include <esp_now.h>
#include <LIDARLite.h>
#include <GlobalVar.h>

#define BUTTON_PIN 2
#define BATTERY 34

Adafruit_BME280 bme;
LIDARLite myLidar;
int cal_cnt = 0;
#define STICK_HEIGHT 60 // in cm

uint8_t broadcastAddress[] = {0xFF, 0xFF, 0xFF, 0xFF, 0xFF, 0xFF}; // wpisac tu mac address

// Define variables to store BME280 readings to be sent
float temperature = 0;
float humidity = 0;
float pressure = 0;
float distance = 0;
// Variable to store if sending data was successful
String success;

char col;
unsigned int PMSa1 = 0, PMSa2_5 = 0, PMSa10 = 0, FMHDSa = 0, TPSa = 0, HDSa = 0, PMSb1 = 0, PMSb2_5 = 0, PMSb10 = 0, FMHDSb = 0, TPSb = 0, HDSb = 0;
unsigned int PMS1 = 0, PMS2_5 = 0, PMS10 = 0, FMHDS = 0, TPS = 0, HDS = 0, CR1 = 0, CR2 = 0;
unsigned char buffer_RTT[40] = {}; // Serial buffer; Received Data
char tempStr[15];

// Structure example to send data
// Must match the receiver structure
typedef struct struct_message
{
  char nodeId[16];
  float batteryLevel;
  float temperature;
  float humidity;
  float pressure;
  int32_t snowDepth;
  uint32_t pm1;
  uint32_t pm25;
  uint32_t pm10;
  bool pair;
} struct_message;

// Create a struct_message called BME280Readings to hold sensor readings
struct_message Readings;

esp_now_peer_info_t peerInfo;

// Callback when data is sent
void OnDataSent(const uint8_t *mac_addr, esp_now_send_status_t status)
{
  Serial.print("\r\nLast Packet Send Status:\t");
  Serial.println(status == ESP_NOW_SEND_SUCCESS ? "Delivery Success" : "Delivery Fail");
  if (status == 0)
  {
    success = "Delivery Success :)";
  }
  else
  {
    success = "Delivery Fail :(";
  }
}

void setup()
{
  // Init Serial Monitor
  Serial.begin(115200);
  Serial2.begin(9600);
  pinMode(BATTERY, INPUT);
  pinMode(BUTTON_PIN, INPUT_PULLUP);

  // Init BME280 sensor
  bool status = bme.begin(0x77);
  if (!status)
  {
    Serial.println("Could not find a valid BME280 sensor, check wiring!");
    while (1)
      ;
  }

  // Init LIDAR
  myLidar.begin(0, true);
  myLidar.configure(3);

  // Set device as a Wi-Fi Station
  WiFi.mode(WIFI_STA);
  esp_wifi_set_promiscuous(true);                 // Enable promiscuous mode
  esp_wifi_set_channel(1, WIFI_SECOND_CHAN_NONE); // Set the specific channel
  esp_wifi_set_promiscuous(false);

  // Init ESP-NOW
  if (esp_now_init() != ESP_OK)
  {
    Serial.println("Error initializing ESP-NOW");
    return;
  }

  // Once ESPNow is successfully Init, we will register for Send CB to
  // get the status of Trasnmitted packet
  esp_now_register_send_cb(OnDataSent);

  // Register peer
  memcpy(peerInfo.peer_addr, broadcastAddress, 6);
  peerInfo.channel = 1;
  peerInfo.encrypt = false;

  // Add peer
  if (esp_now_add_peer(&peerInfo) != ESP_OK)
  {
    Serial.println("Failed to add peer");
    return;
  }
}

void getReadings()
{
  temperature = bme.readTemperature();
  humidity = bme.readHumidity();
  pressure = (bme.readPressure() / 100.0F);
  distance = myLidar.distance(); // With bias correction
}

bool firstLoop = true;

void loop()
{
  while (Serial2.available() > 40) // Check whether there is any serial data
  {
    for (int i = 0; i < 40; i++)
    {
      col = Serial2.read();
      buffer_RTT[i] = (char)col;
      delay(2);
    }
    Serial2.flush();
    CR1 = (buffer_RTT[38] << 8) + buffer_RTT[39];
    CR2 = 0;
    for (int i = 0; i < 38; i++)
      CR2 += buffer_RTT[i];

    if (CR1 == CR2) // Check
    {
      PMSa1 = buffer_RTT[10];      // Read PM1 high 8-bit data
      PMSb1 = buffer_RTT[11];      // Read PM1 low 8-bit data
      PMS1 = (PMSa1 << 8) + PMSb1; // PM1 data

      PMSa2_5 = buffer_RTT[12];          // Read PM2.5 high 8-bit data
      PMSb2_5 = buffer_RTT[13];          // Read PM2.5 low 8-bit data
      PMS2_5 = (PMSa2_5 << 8) + PMSb2_5; // PM2.5 data

      PMSa10 = buffer_RTT[14];        // Read PM10 high 8-bit data
      PMSb10 = buffer_RTT[15];        // Read PM10 low 8-bit data
      PMS10 = (PMSa10 << 8) + PMSb10; // PM10 data

      FMHDSa = buffer_RTT[28];        // Read Formaldehyde High 8-bit
      FMHDSb = buffer_RTT[29];        // Read Formaldehyde Low 8-bit
      FMHDS = (FMHDSa << 8) + FMHDSb; // Formaldehyde value
      TPSa = buffer_RTT[30];          // Read Temperature High 8-bit
      TPSb = buffer_RTT[31];          // Read Temperature Low 8-bit
      TPS = (TPSa << 8) + TPSb;       // Temperature value
      HDSa = buffer_RTT[32];          // Read Humidity High 8-bit
      HDSb = buffer_RTT[33];          // Read Humidity Low 8-bit
      HDS = (HDSa << 8) + HDSb;
    }
    else
    {
      Serial.println("checked NOT ok");
      PMS1 = 0;
      PMS2_5 = 0;
      PMS10 = 0;
      // PMS = 0;
      TPS = 0;
      HDS = 0;
      if (!firstLoop)
        ESP.restart();
    }
  }

  getReadings();

  // Set values to send
  Readings.temperature = temperature; //(float)TPS / 10.f;
  Readings.humidity = humidity;       //(float)HDS / 10.f;
  Readings.pressure = pressure;
  strcpy(Readings.nodeId, UID);

  // lidar distance
  Readings.snowDepth = distance;
  Readings.batteryLevel = ((float)analogRead(BATTERY) / 4095.f) * 2.f * 3.3f;

  Readings.pair = !digitalRead(BUTTON_PIN);
  // pm values - airQualitySensor
  Readings.pm1 = PMS1;
  Readings.pm10 = PMS10;
  Readings.pm25 = PMS2_5;
  Serial.println("TEST PRINT: ");
  Serial.println(temperature);
  Serial.println(humidity);
  Serial.println(pressure);
  Serial.println(distance);
  Serial.println(PMS1);
  Serial.println(PMS10);
  Serial.println(PMS2_5);
  Serial.println(TPS);
  Serial.println(HDS);
  Serial.println(Readings.batteryLevel);
  Serial.println(analogRead(BATTERY));
  Serial.print("pair: ");
  Serial.println(Readings.pair);
  Serial.println();

  if (PMS2_5 != 0 && PMS10 != 0 && PMS1 != 0)
    firstLoop = false;

  // Send message via ESP-NOW
  if (!firstLoop)
  {
    esp_err_t result = esp_now_send(broadcastAddress, (uint8_t *)&Readings, sizeof(Readings));

    if (result == ESP_OK)
    {
      Serial.println("Sent with success");
    }
    else
    {
      Serial.println("Error sending the data");
    }
  }

  delay(firstLoop ? 1000 : 10000);
}

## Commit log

2024-12-04 improved account page plus 6digit code button, modified skeleton charts
2024-12-04 add sensor data endpoint
2024-12-04 move 'created' property to sensor data
2024-12-04 [frontend] fix socket connection
2024-12-04 sensors and espnow communcation (#25)
2024-12-04 working node sensors with espnow (#29)
2024-12-04 @matij/pcb (#30)
    * pcb noe
    * changes
    [node.kicad_pcb, node.kicad_sch]
2024-12-04 @matij/case stl (#33)
    * added STL files
    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
    [Lid.stl, LidMount.stl, LidarMount.stl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]
2024-12-04 @matij/schem gateway (#34)
    * schem gateway
    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
    [gateway.kicad_pcb, gateway.kicad_sch, node.kicad_sch]
2024-12-04 Integration hardware (#35)
    [node.kicad_sch]
2024-12-04 better case (#36)
2024-12-04 [frontend] fix live sensor data parsing
2024-12-04 [frontend] display stations owned by the current user in their private panel
2024-12-04 manual flow in CLI (#69)
2024-12-04 display battery level
2024-12-04 add snackbar with battery level
